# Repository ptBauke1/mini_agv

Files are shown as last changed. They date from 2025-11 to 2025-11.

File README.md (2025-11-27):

# 🤖 Mini AGV - Autonomous Guided Vehicle

Robô seguidor de linha com controle PID, detecção de obstáculos e monitoramento em tempo real via dashboard web.

## 🎯 Sobre o Projeto

Este projeto implementa um AGV (Automated Guided Vehicle) utilizando o microcontrolador **RP2040**, capaz de seguir linhas de forma autônoma com controle PID ajustável, detectar obstáculos e transmitir telemetria em tempo real para um dashboard web.

### Características Principais

- **Seguidor de linha** com 8 sensores infravermelhos multiplexados
- **Controle PID** ajustável em tempo real via Bluetooth
- **Detecção de obstáculos** com sensor ultrassônico HC-SR04
- **Dashboard web** para visualização de telemetria e controle remoto
- **Comunicação Bluetooth** para comandos e telemetria
- **Sistema de calibração** automático dos sensores

---

## ✨ Funcionalidades

- ✅ Seguimento de linha preto/branco com controle PID
- ✅ Detecção e parada automática diante de obstáculos (< 120mm)
- ✅ Telemetria em tempo real (200ms): PWM dos motores, erro de linha, distância
- ✅ Dashboard web com gráficos ao vivo (Chart.js)
- ✅ Comandos via Bluetooth: START, STOP, CALIBRATE, PID
- ✅ Calibração automática dos sensores de linha
- ✅ Ajuste de constantes PID em tempo real
- ✅ Controle de velocidade base dos motores

---

## 🔧 Hardware

### Lista de Materiais

#### Barra de Sensor

| Componente | Quantidade | Descrição |
|---|---|---|
| **Sensor de linha IR** | 8 | QRE1113 |
| **Resistor 220 Ohms** | 8 | 220 Ohms |
| **Resistor 22k Ohms** | 8 | 22k Ohms|
| **CD4051** | 1 | Multiplexador analógico 8:1 |

#### Placa Principal

| Componente | Quantidade | Descrição |
|---|---|---|
| **Raspberry Pi Pico** | 1 | Microcontrolador principal (RP2040) |
| **HC-SR04** | 1 | Sensor ultrassônico para detecção de obstáculos |
| **L298N** | 1 | Drivers de motor DC (ou 1 módulo duplo) |
| **Motor DC** | 2 | Motores DC 3-6V |
| **HC-05/06** | 1 | Módulo Bluetooth (UART) |
| **LM7805** | 1 | Regulador 5V |
| **LM1117** | 1 | Regulador 3v3|
| **Capacitor 10uF** | 4 | Capacitor Eletrolitico 10uF |
| **Resistor 10k Ohms**| 4 | Resistor 10k Ohms |
| **2N7000** | 2 | MOSFET 2N7000 |
| **Diodo** | 1 | Diodo 1N4007 |

#### Chassi
| Componente | Quantidade | Descrição |
|---|---|---|
| **Placa de MDF** | 1 | Placa de MDF de 3mm para corte do chassi |
| **Rodas** | 2 | Rodas de 65mm |
| **PLA** | 1 | Carretel de filamento PLA para impressão de peças |
| **Elasticos** | 10 | Elasticos de dinheiro para serem colocados nas rodas |
| **Parafusos e Porcas** | 6 | Parafusos e Porcas M3 |
| **Feltro** | 1 | Feltro para terceiro ponto de apoio |
### Pinagem

| Periférico | Pino(s) Pico W | Descrição |
|---|---|---|
| **Bluetooth (UART1)** | GPIO 8 (TX), GPIO 9 (RX) | Comunicação serial 9600 baud |
| **Ultrassônico** | GPIO 2 (TRIG), GPIO 3 (ECHO) | Medição de distância |
| **Sensores de Linha** | GPIO 18, 19, 20 (Mux S0-S2), GPIO 26 (ADC0) | 8 sensores via multiplexador |
| **Motor Esquerdo** | GPIO 11 (ENA), GPIO 14 (IN1A), GPIO 15 (IN2A) | Controle PWM + direção |
| **Motor Direito** | GPIO 10 (ENB), GPIO 12 (IN1B), GPIO 13 (IN2B) | Controle PWM + direção |

---

## 💻 Software

### Tecnologias Utilizadas

#### Firmware (C++)
- **Pico SDK 2.2.0** - Framework oficial da Raspberry Pi
- **C++17** - Linguagem principal
- **CMake** - Sistema de build
- **bt_kmn** - Biblioteca customizada para Bluetooth com sistema de comandos

#### Dashboard (Web)
- **Python 3.x** - Servidor WebSocket/HTTP
- **asyncio + websockets** - Comunicação assíncrona
- **pyserial** - Interface com porta serial Bluetooth
- **HTML5 + JavaScript** - Frontend do dashboard
- **Chart.js** - Visualização de telemetria em tempo real

### Arquitetura

```
Raspberry Pi Pico (Firmware C++)
         ↓ Bluetooth UART (9600 baud)
    Módulo HC-05/06
         ↓ USB Serial (COM Port)
 Computador (Python Server)
         ↓ WebSocket (8765)
   Dashboard Web (HTML/JS)
```

---

## 🔨 Montagem

### Esquemas de Ligação

#### Esquema Principal - Motores, Bluetooth e Ultrassônico

<p align="center">
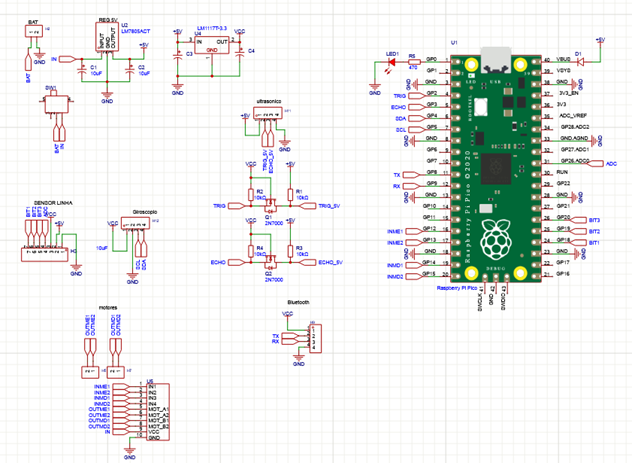
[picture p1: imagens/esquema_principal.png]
Esquema Principal
  
</p>

#### Esquema dos Sensores de Linha (Multiplexador)

<p align="center">
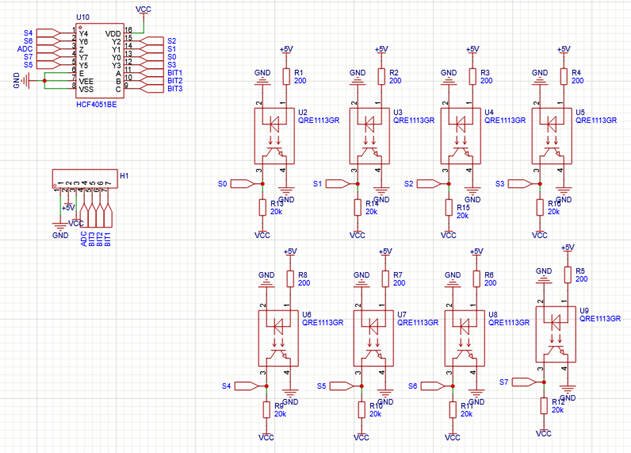
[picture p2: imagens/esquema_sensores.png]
Esquema Sensores
  
</p>

### Foto da Montagem Final

<p align="center">
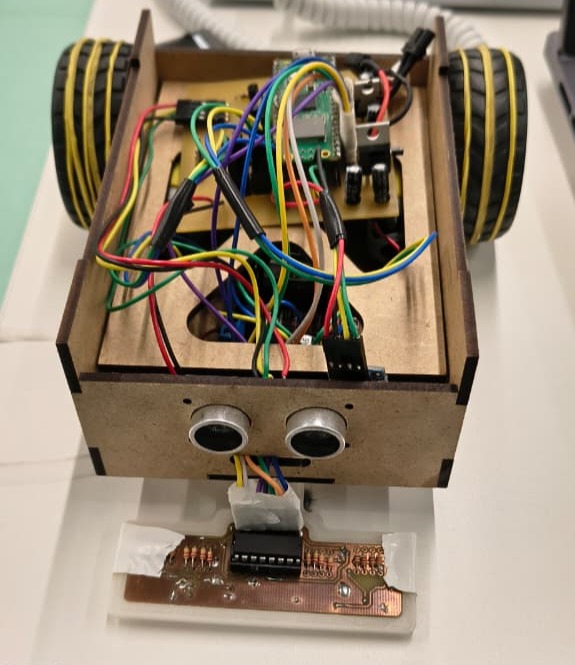
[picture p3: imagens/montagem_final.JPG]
Montagem Final
  
</p>

<p align="center"><em>Robô montado com todos os componentes integrados</em></p>
---

## 🚀 Instalação e Configuração

### Pré-requisitos

- **Raspberry Pi Pico SDK** (2.2.0 ou superior)
- **CMake** (3.13+)
- **Ninja** (build system)
- **Python 3.8+** com pip
- **Git** (para clonar submódulos)

### Passo 1: Clonar o Repositório

```bash
git clone https://github.com/ptBauke1/mini_agv.git
cd mini_agv
git submodule update --init --recursive
```

### Passo 2: Compilar o Firmware

```bash
# Criar diretório de build
mkdir build
cd build

# Configurar CMake
cmake ..

# Compilar
ninja
```

O arquivo `projeto_agvs.uf2` será gerado em `build/`.

### Passo 3: Instalar Dependências Python (Dashboard)

```bash
cd dashboard
python -m venv .venv
source .venv/bin/activate  # Linux/Mac
# ou
.venv\Scripts\activate     # Windows

pip install asyncio websockets pyserial
```

### Passo 4: Flashear o Pico W

1. Conecte o Pico W ao PC segurando o botão **BOOTSEL**
2. Copie `build/projeto_agvs.uf2` para o drive USB que apareceu
3. O Pico reiniciará automaticamente com o novo firmware

---

## 🎮 Uso

### Iniciar o Sistema

1. **Ligar o robô** (conectar bateria)
2. **Conectar o módulo Bluetooth** ao computador
3. **Iniciar o servidor Python**:
   ```bash
   cd dashboard
   python bt_websocket_server.py
   ```
4. **Abrir o dashboard** no navegador:
   ```
   http://localhost:8080/dashboard.html
   ```

### Calibração dos Sensores

1. No dashboard, clique em **"Connect WS"** para conectar ao servidor
2. Selecione a porta COM do Bluetooth e clique em **"Connect COM"**
3. Posicione o robô sobre a linha (metade dos sensores no preto, metade no branco)
4. Clique em **"🎯 Calibrate Sensors"**
5. **Movimente o robô lentamente** sobre a linha por ~10 segundos
6. Aguarde a mensagem "Calibration COMPLETE"

### Operação Normal

1. Posicione o robô sobre a linha
2. Clique em **"▶️ Start Robot"**
3. Ajuste constantes PID se necessário (painel "⚙️ PID Control")
4. Monitore telemetria em tempo real nos gráficos

---

## 📊 Dashboard Web

### Recursos do Dashboard

- **Status de Conexão**: WebSocket e COM Port separados
- **Controles do Robô**: START, STOP, CALIBRATE
- **Painel PID**: Ajuste de Kp, Ki, Kd em tempo real
- **Indicador de Obstáculos**: Visual + alerta sonoro (animado)
- **Métricas Instantâneas**: PWM motores, erro de linha, distância
- **Gráficos em Tempo Real**: 
  - PWM dos motores (esquerdo/direito)
  - Erro do seguidor de linha
  - Distância do sensor ultrassônico
- **Log de Dados**: Histórico de comandos e eventos

### Captura de Tela

<p align="center">
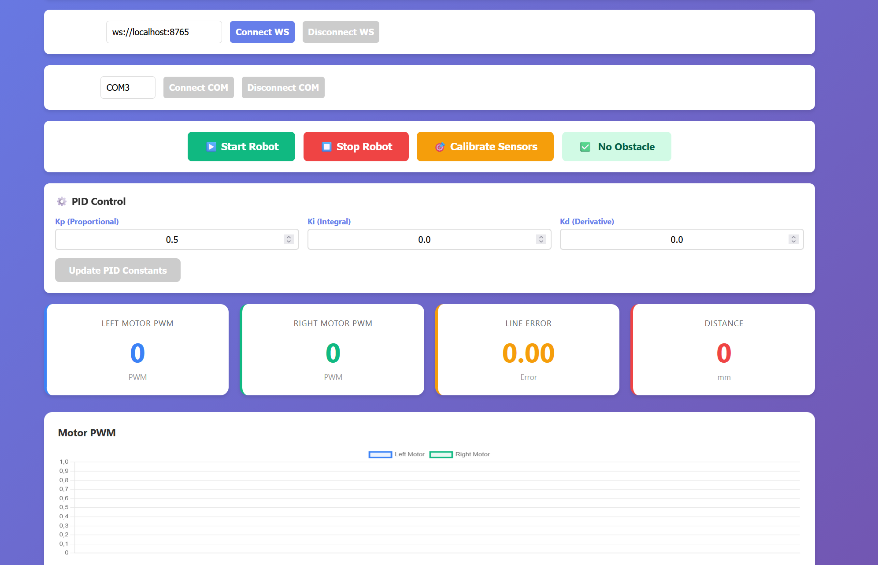
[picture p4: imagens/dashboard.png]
Dashboard Web
  
</p>

<p align="center"><em>Interface do dashboard com gráficos em tempo real e controles do robô</em></p>

---

## 📡 Comandos Bluetooth

O robô aceita os seguintes comandos via Bluetooth (9600 baud, `\n` terminador):

### Comandos Básicos

| Comando | Formato | Descrição | Resposta |
|---|---|---|---|
| **START** | `START` | Inicia o robô | `Robot STARTED` |
| **STOP** | `STOP` | Para o robô e motores | `Robot STOPPED` |
| **CALIBRATE** | `CALIBRATE` | Calibra sensores de linha | `Calibration COMPLETE` |

### Ajuste de PID

| Comando | Formato | Exemplo | Descrição |
|---|---|---|---|
| **PID** | `PID <kp> <ki> <kd>` | `PID 0.3 0.0 0.02` | Define constantes PID |
| **PID** | `PID` (sem parâmetros) | `PID` | Consulta valores atuais |

**Resposta**: `PID updated: Kp=0.300 Ki=0.000 Kd=0.020`

### Formato de Telemetria

A cada 200ms, o robô envia automaticamente:
```
L:<left_pwm>,R:<right_pwm>,E:<error>,D:<distance>
```
**Exemplo**: `L:850,R:750,E:-1.25,D:350`

Veja [COMMANDS.md](COMMANDS.md) para documentação completa.

---

## 📁 Estrutura do Projeto

```
projeto_agvs/
├── CMakeLists.txt              # Configuração CMake principal
├── projeto_agvs.cpp            # Código principal (main loop, PID)
├── pico_sdk_import.cmake       # Importação do Pico SDK
├── COMMANDS.md                 # Documentação detalhada de comandos
├── README.md                   # Este arquivo
│
├── include/                    # Headers personalizados
│   ├── sensors.hpp             # Sensores de linha + ultrassônico
│   ├── motors.hpp              # Controle de motores L298N
│   ├── gyro.hpp                # Giroscópio MPU6050
│   └── agv_commands.h          # Sistema de comandos
│
├── src/                        # Implementações
│   ├── sensors.cpp
│   ├── motors.cpp
│   ├── gyro.cpp
│   └── agv_commands.cpp        # Comandos Bluetooth (START, STOP, PID, etc.)
│
├── bluetooth_sdk/              # Biblioteca bt_kmn (submódulo)
│   ├── include/bt_kmn/
│   │   ├── bluetooth.h
│   │   └── commands.h
│   └── src/
│       ├── bluetooth.c
│       └── commands.c
│
├── dashboard/                  # Interface web
│   ├── bt_websocket_server.py # Servidor Python (WebSocket + Serial)
│   └── dashboard.html          # Frontend (Chart.js + controles)
│
└── build/                      # Arquivos de compilação (gerado)
    └── projeto_agvs.uf2        # Firmware final
```

---

## 🔬 Algoritmo de Controle

### Controle PID

O robô utiliza um controlador PID para seguir a linha:

```
erro = posição_calculada - centro_linha
integral += erro
derivada = erro - erro_anterior
correção = Kp × erro + Ki × integral + Kd × derivada

pwm_esquerdo = base_speed + correção
pwm_direito = base_speed - correção
```

**Valores padrão**:
- Kp = 1.75 (proporcional)
- Ki = 0.0 (integral - desabilitado para evitar overshooting)
- Kd = 520.0 (derivativo)
- Base Speed = 800 (PWM de 0-1023)

### Detecção de Obstáculos

- Leitura do ultrassônico a cada 10ms
- Limiar de parada: **120mm**
- Timeout de leitura: 50ms
- Ação: Para motores automaticamente (`robot_enabled = false`)

---

## 🐛 Troubleshooting

### Problema: Sensores de linha não calibram corretamente
**Solução**: 
- Verificar se os 8 sensores estão conectados ao multiplexador
- Aumentar contraste da linha (preto mais escuro, branco mais claro)
- Ajustar altura dos sensores (3-5mm da superfície)

### Problema: Ultrassônico retorna 0 ou 65535
**Solução**:
- Verificar pino ECHO (deve estar em nível lógico compatível - usar divisor de tensão se necessário)
- Aumentar timeout em `sensors.cpp` (padrão 50ms)
- Verificar alimentação do HC-SR04 (5V estável)

### Problema: Dashboard não conecta
**Solução**:
- Verificar firewall (liberar porta 8765 WebSocket + 8080 HTTP)
- Conferir porta COM do Bluetooth (ajustar em `bt_websocket_server.py` ou no dashboard)
- Testar comunicação serial: `python -m serial.tools.miniterm COM3 9600`

### Problema: Motores não respondem
**Solução**:
- Verificar alimentação dos drivers L298N (bateria carregada)
- Conferir jumpers de enable nos L298N
- Testar PWM com osciloscópio/LED (pinos 10 e 11 do Pico)

---

## 📚 Referências

- [Raspberry Pi Pico SDK Documentation](https://www.raspberrypi.com/documentation/pico-sdk/)
- [Chart.js Documentation](https://www.chartjs.org/docs/)

---

**Última atualização**: Novembro 2025

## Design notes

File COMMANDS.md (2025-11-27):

# Comandos Bluetooth do AGV

Este documento descreve todos os comandos disponíveis para controle do AGV via Bluetooth.

## Sistema de Comandos

Os comandos seguem o formato da biblioteca `bt_kmn`:
- Comandos simples: `COMANDO\n`
- Comandos com parâmetros: `COMANDO=parametros\n`

## Lista de Comandos

### 1. START
**Uso**: `START`  
**Descrição**: Inicia o robô e habilita o seguidor de linha  
**Exemplo**:
```
START
```
**Resposta**: `Robot STARTED`

---

### 2. STOP
**Uso**: `STOP`  
**Descrição**: Para o robô imediatamente e desabilita todos os motores  
**Exemplo**:
```
STOP
```
**Resposta**: `Robot STOPPED`

---

### 3. STATUS
**Uso**: `STATUS`  
**Descrição**: Retorna o estado atual do robô (rodando ou parado)  
**Exemplo**:
```
STATUS
```
**Resposta**: `Robot is RUNNING` ou `Robot is STOPPED`

---

### 4. SPEED
**Uso**: `SPEED=<valor>` ou `SPEED` (consulta)  
**Descrição**: Define ou consulta a velocidade base dos motores  
**Parâmetros**:
- `valor`: Velocidade entre 0 e 1000 (PWM)

**Exemplos**:
```
SPEED=500        # Define velocidade para 500
SPEED            # Consulta velocidade atual
```
**Resposta**: `Base speed set to 500` ou `Current speed: 500`

---

### 5. PID
**Uso**: `PID=<kp>,<ki>,<kd>` ou `PID` (consulta)  
**Descrição**: Define ou consulta as constantes do controlador PID  
**Parâmetros**:
- `kp`: Constante proporcional
- `ki`: Constante integral
- `kd`: Constante derivativa

**Exemplos**:
```
PID=1.5,0.0,0.5  # Define Kp=1.5, Ki=0.0, Kd=0.5
PID              # Consulta valores atuais
```
**Resposta**: `PID set to Kp=1.500 Ki=0.000 Kd=0.500`

---

### 6. HELP
**Uso**: `HELP`  
**Descrição**: Lista todos os comandos disponíveis  
**Exemplo**:
```
HELP
```
**Resposta**: Lista formatada de comandos

---

## Telemetria Automática

O AGV envia automaticamente dados de telemetria a cada 200ms:

**Formato**: `L:<pwm_esq>,R:<pwm_dir>,E:<erro>,D:<distancia>\n`

**Exemplo**:
```
L:150,R:180,E:1.23,D:450
```

Onde:
- `L`: PWM do motor esquerdo (0-255)
- `R`: PWM do motor direito (0-255)
- `E`: Erro do seguidor de linha (float)
- `D`: Distância do obstáculo em mm

---

## Usando via Dashboard Web

O dashboard web envia comandos automaticamente quando você clica nos botões:
- **▶️ Start Robot** → envia `START`
- **⏹️ Stop Robot** → envia `STOP`

---

## Usando via Terminal Serial

Você pode enviar comandos manualmente usando qualquer terminal serial (PuTTY, Arduino IDE, etc.):

1. Conecte à porta COM do Bluetooth (9600 baud)
2. Digite o comando seguido de Enter
3. Observe a resposta

**Exemplo de sessão**:
```
> HELP
=== AGV Commands ===
START        - Start robot
STOP         - Stop robot
...

> START
Robot STARTED

> SPEED=600
Base speed set to 600

> STATUS
Robot is RUNNING

> STOP
Robot STOPPED
```

---

## Adicionando Novos Comandos

Para adicionar um novo comando, edite `src/agv_commands.cpp`:

```cpp
// Command: MEU_COMANDO
// Usage: MEU_COMANDO=<param>
// Description: Descrição do comando
BT_COMMAND_DEFINE(MEU_COMANDO) {
    // params contém os parâmetros após o '='
    // Implemente a lógica aqui
    
    Bluetooth_SendMessage("Resposta do comando\n");
}
```

O sistema de comandos usa macros da biblioteca `bt_kmn` para registrar automaticamente os comandos disponíveis.

---

## Notas Técnicas

1. **Terminação**: Todos os comandos devem terminar com `\n`
2. **Case Sensitive**: Os comandos são case-sensitive (use maiúsculas)
3. **Buffer**: Comandos limitados a 128 caracteres
4. **Delimitador**: Parâmetros são separados por `=`
5. **Múltiplos Parâmetros**: Use vírgulas: `CMD=param1,param2,param3`

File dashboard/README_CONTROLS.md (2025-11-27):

# Sistema de Controle Remoto do AGV

## Funcionalidades Adicionadas

### 1. **Botões de Controle**
- **▶️ Start Robot**: Inicia o movimento do AGV (habilita motores)
- **⏹️ Stop Robot**: Para o AGV imediatamente (desabilita motores)

### 2. **Indicador de Obstáculos**
- **✅ No Obstacle**: Exibido quando não há obstáculos detectados
- **⚠️ Obstacle at Xmm**: Pisca em vermelho quando um obstáculo é detectado a menos de 120mm
- Animação de pulso para alertar visualmente

## Arquitetura

### Fluxo de Comandos
```
Dashboard → WebSocket → Python Server → Serial/Bluetooth → Microcontrolador
```

### Fluxo de Detecção de Obstáculos
```
Sensor Ultrassônico → Microcontrolador → Bluetooth → Python → WebSocket → Dashboard
```

## Protocolo de Comunicação

### Comandos (Dashboard → MCU)
- `CMD:START\n` - Inicia o robô
- `CMD:STOP\n` - Para o robô

### Telemetria (MCU → Dashboard)
- `L:<pwm>,R:<pwm>,E:<erro>,D:<distancia>\n` - Dados em tempo real

## Comportamento do Sistema

### Estado Inicial
- Robô desabilitado (motores parados)
- Aguardando comando START

### Após START
- Motores habilitados
- Seguidor de linha ativo
- Detecção de obstáculos ativa
- Se obstáculo < 120mm → motores param automaticamente

### Após STOP
- Motores desabilitados imediatamente
- Telemetria continua sendo enviada
- Sensores continuam lendo (sem atuação)

## Segurança

1. **Parada de Emergência**: Botão STOP funciona a qualquer momento
2. **Detecção Automática**: Obstáculos param o robô mesmo sem comando
3. **Estado Persistente**: Robô sempre inicia desabilitado
4. **Feedback Visual**: Indicador de obstáculo em tempo real

## Uso

1. Conecte o dashboard ao WebSocket
2. Aguarde telemetria (confirma conexão)
3. Clique **START** quando pronto
4. Monitore obstáculos no indicador
5. Use **STOP** para parada de emergência

## Detalhes Técnicos

- **Threshold de Obstáculo**: 120mm
- **Taxa de Atualização**: 200ms (5Hz)
- **Latência de Comando**: <50ms
- **Animação de Alerta**: 1s pulse cycle

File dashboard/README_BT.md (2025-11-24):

# Bluetooth Telemetry Receiver

## Installation

1. Install Python packages:
```bash
pip install pyserial matplotlib websockets
```

## Usage Options

### 1. Simple Console Output (`bt_receiver.py`)

Quick view of telemetry in the terminal.

```bash
python bt_receiver.py
```

### 2. Interactive Matplotlib Dashboard (`bt_dashboard.py`)

Real-time graphs with matplotlib (desktop app).

```bash
python bt_dashboard.py
```

### 3. HTML Web Dashboard (`dashboard.html` + `bt_websocket_server.py`)

Modern web-based dashboard accessible from any browser!

**Steps:**
1. Edit `bt_websocket_server.py`:
   - Change `SERIAL_PORT = 'COM3'` to your actual port

2. Start the WebSocket server:
```bash
python bt_websocket_server.py
```

3. Open `dashboard.html` in your web browser

4. Click "Connect" button in the dashboard

**Features:**
- 📊 Real-time charts with Chart.js
- 💎 Modern, beautiful UI
- 📱 Responsive design
- 📝 Live data log
- 🎨 Color-coded metrics

## Configuration

For all scripts, find your Bluetooth COM port:
- Open Device Manager → Ports (COM & LPT)
- Look for your Bluetooth device (e.g., COM3, COM4)

## Output Example (Console)
```
[14:23:45] Left PWM:  650 | Right PWM:  750 | Error:  -1.23 | Distance:  245 mm
[14:23:46] Left PWM:  680 | Right PWM:  720 | Error:   0.45 | Distance:  243 mm
```

## Troubleshooting

- **"Access denied"**: Close any other program using the COM port
- **"Port not found"**: Check the COM port number in Device Manager
- **No data**: Make sure the Bluetooth connection is established
- **WebSocket error**: Ensure the server is running before opening the HTML dashboard

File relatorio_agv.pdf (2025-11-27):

Plataforma autônoma para logística

Eliana So 1

; Pedro Bauke 1

; Andressa Martins 2

; Rodrigo França 2

1 Aluno do Instituto Mauá de Tecnologia (IMT); 2 Professor do Instituto Mauá de Tecnologia (IMT).

Resumo. Este projeto apresenta o desenvolvimento de um protótipo de Veículo Guiado Autonomamente (AGV) voltado para a logística interna, motivado pela crescente demanda do e-commerce no Brasil. A plataforma robótica foi construída utilizando materiais acessíveis, como MDF e impressão 3D, e é controlada por um microcontrolador RP2040. O sistema de navegação baseia-se na leitura de linha por meio de sensores de refletância e um algoritmo de controle PID, integrando também detecção de obstáculos via ultrassom e telemetria em tempo real via Bluetooth para um dashboard web. Durante os testes, desafios relacionados à aderência mecânica e ao driver de potência exigiram a substituição de componentes (do driver MX1508 para o L298N) e adaptações nas rodas. Apesar das dificuldades e da não implementação do módulo inercial (MPU) devido ao prazo, o protótipo final atingiu os objetivos propostos, demonstrando capacidade de navegar autonomamente, interromper o movimento ao detectar obstáculos e comunicar dados operacionais com sucesso.

Introdução

O varejo online tem, cada vez mais, se tornado a opção primária para compras dos brasileiros, como mostra um estudo realizado pela FGV, que expõe que as vendas do e-commerce já representam mais de 10% do faturamento do setor desde outubro de 2021 e em fevereiro de 2025 chegaram a representar 17,8%. A Figura 1 apresenta um histórico da parcela do e-commerce no varejo.

Figura 1 – Fatia de e-commerce no varejo

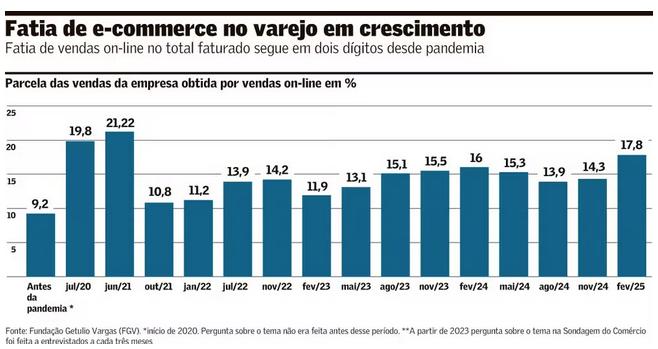
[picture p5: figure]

Fonte: Valor Econômico (2025)

Olhando para esse cenário, diversas empresas estão investindo em centros de distribuição e logística, e maneiras de automatizar esses centros. Uma dessas maneiras é com a utilização de AGVs (Autonomous Guided Vehicles), ou robôs autônomos que são capazes de se movimentar e carregar cargas dentro dos armazéns, facilitando e agilizando a logística.

Observando essa tendência, optou-se pelo desenvolvimento de um protótipo de uma plataforma capaz de detectar obstáculos e navegar de forma autônoma em ambientes controlados, necessitando apenas de uma linha para poder seguir e andar de um ponto a outro.

Material e Métodos

Por se tratar de um protótipo, optou-se por utilizar materiais de fácil acesso, como MDF e filamento plástico, e métodos de fabricação rápidos, como corte à laser e impressão 3D, para poder iterar de maneira rápida entre versões. A Figura 2 apresenta a montagem final do protótipo.

Figura 2 – Montagem Final

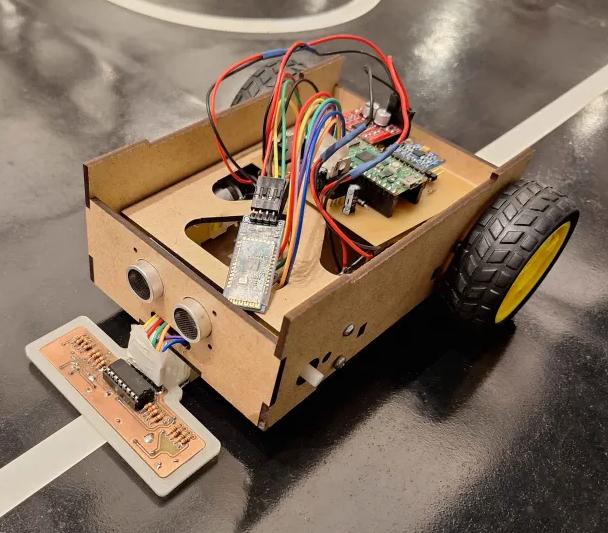
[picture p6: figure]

Fonte: Os Autores (2025)

Mecânica

Por se tratar de um protótipo, o robô possui dimensões pequenas (210 x 155 x 75 mm), a Figura 3 ilustra o projeto mecânico em CAD.

Figura 3 – Vista Explodida em CAD

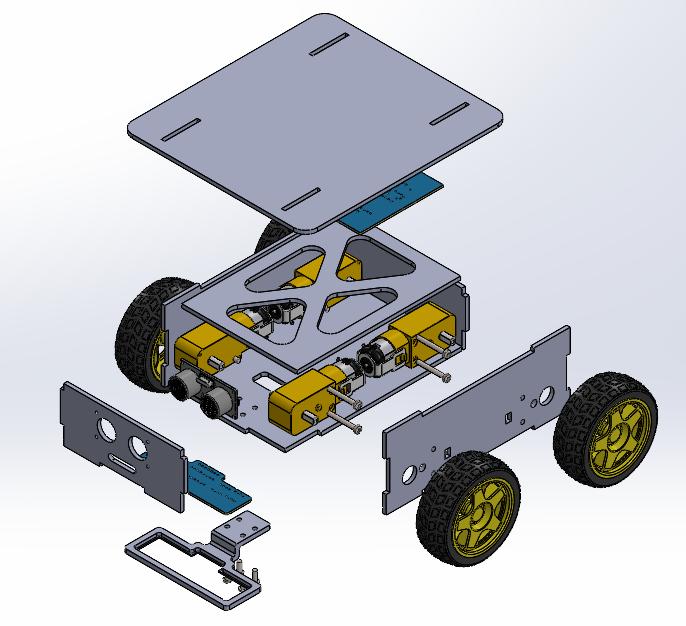
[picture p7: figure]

Fonte: Os autores (2025)

O corpo principal, que possui um formato de caixa, é formado por chapas de MDF fabricadas por corte a laser. Dentro comporta-se os motores, a placa eletrônica principal e o sensor ultrassônico. O robô utiliza-se de 4 motores DC com caixa de redução para ser capaz de transportar objetos mais pesados, devido à melhor distribuição de peso e torque. As rodas são de 65mm de diâmetro e possuem pneus de borracha com um encaixe para os motores.
Foi feito um suporte em impressão 3D, preso por parafusos, para comportar a barra de sensores frontal e mantêm uma distância de 5mm entre o chão e os sensores para a diminuição de erros de leitura.
A mesa superior, onde ficam os itens os quais querem ser movidos, é feito de MDF de 3 mm e é modular, podendo-se criar outros formatos, desde que possuam os encaixes corretos.

Eletrônica

Para a criação e fabricação das placas de circuito impresso,foi montado o diagrama de blocos ilustrado pela Figura 4, que representa de forma simples e clara como cada elemento do circuito se comunica, explicitando como os componentes trocam informações entre si.

Figura 4 – Diagrama de blocos do sistema

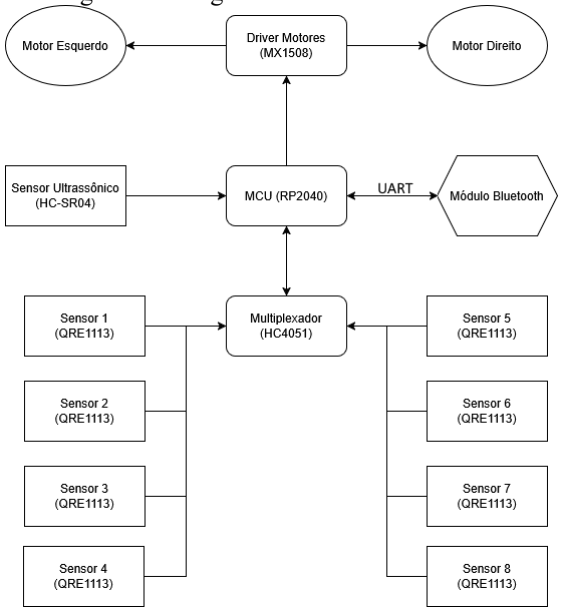
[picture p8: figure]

Fonte: Os Autores (2025)

Optou-se por ter duas placas de circuito separadas, para facilitar a montagem, pois os sensores utilizados para “enxergar” a linha precisam estar próximos ao chão. As Figuras 5 e 6 apresentam os esquemas elétricos das duas placas.

Figura 5 – Esquema elétrico da placa de controle

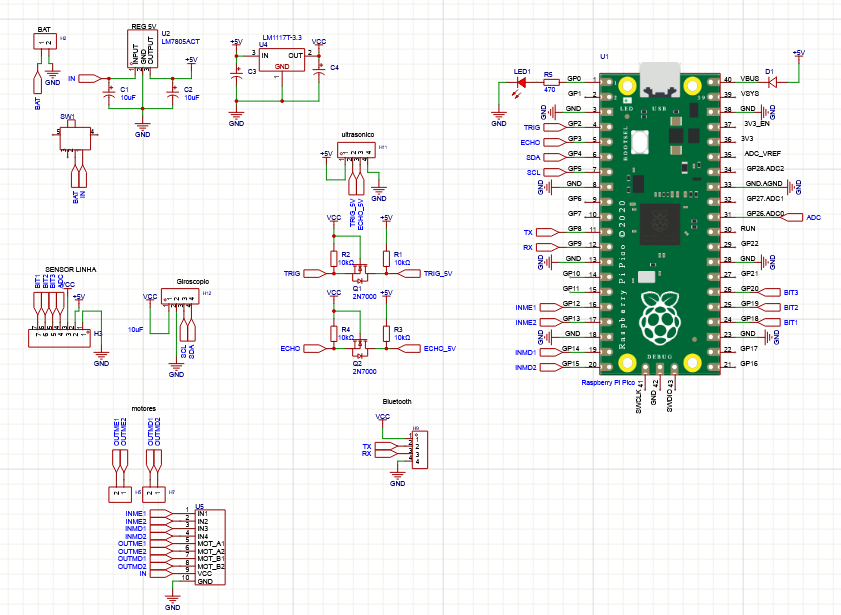
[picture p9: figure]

Fonte: Os Autores (2025)

Figura 6 – Esquema elétrico da placa de sensores

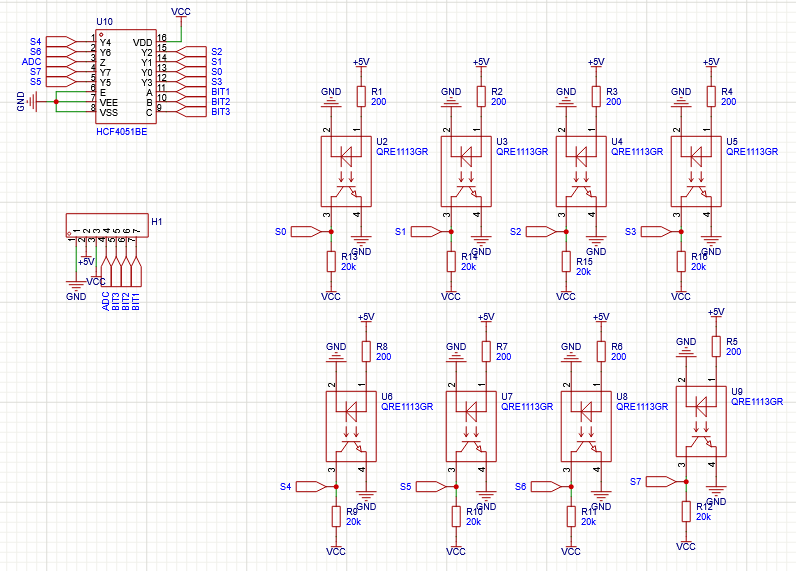
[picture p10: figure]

Fonte: Os Autores (2025)

Na placa dos sensores estão localizados os 8 sensores de refletância QRE1113 e o multiplexador analógico HC4051, que possui 8 canais e é responsável por garantir que todos os sensores possam ser lidos pelo microcontrolador, uma vez que o RP2040 apresenta apenas 3 canais ADC disponíveis. A Figura 7 apresenta a barra dos sensores com os componentes já soldados.

Figura 7 – Barra dos Sensores

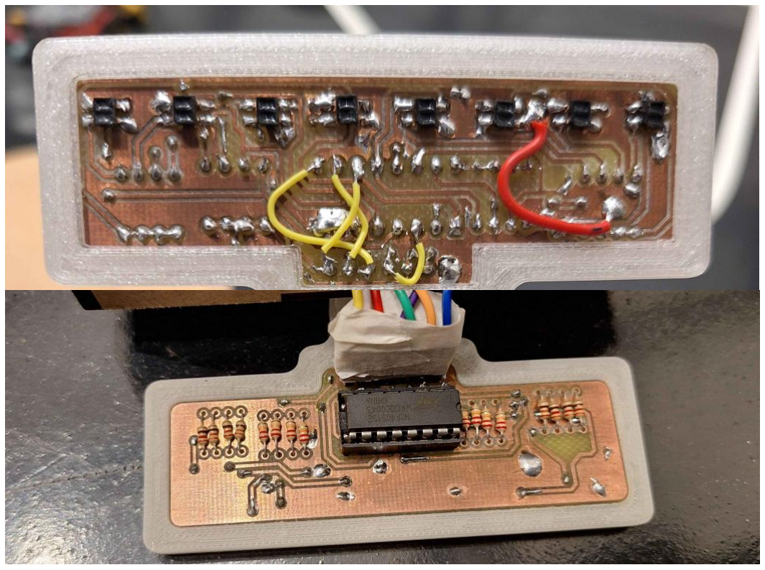
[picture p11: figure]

Fonte: Os Autores (2025)

Para comunicar com o multiplexador é preciso escolher qual porta se deseja ler, para isso, 3 GPIOs do microcontrolador são conectados aos pinos de controle do CI para realizar essa seleção via software.
A PCB de controle contém o microcontrolador e os demais componentes para o funcionamento do robô. Nessa placa também se conecta a bateria, LiPo de 2 células, que alimenta o projeto pois os motores escolhidos suportam até 9V. Para alimentar os demais componentes existem dois reguladores de tensão no circuito, utiliza-se do LM7805 para gerar uma tensão de 5V e um LM1117 que gera a tensão de 3,3V, como pode ser visto na Figura 8.

Figura 8 – Placa de controle

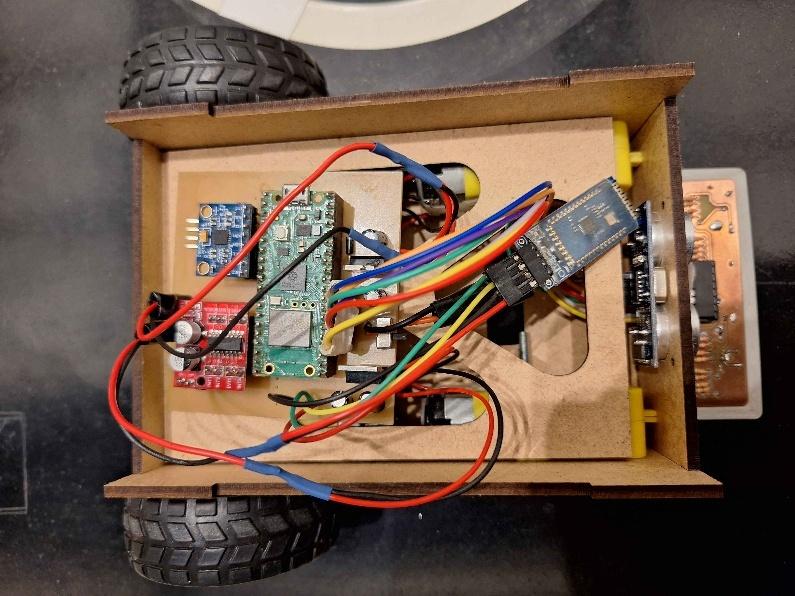
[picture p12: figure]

Fonte: Os Autores (2025)

Para o controle dos motores foi escolhido o Driver MX1508, é uma ponte H dupla onde recebe sinais PWM do microcontrolador e transforma em direção e velocidade aos motores DC. Adicionou-se uma MPU (acelerômetro e giroscópio) com o objetivo de obter a orientação do robô em um determinado percurso a partir da integração da aceleração obtida.

Na placa principal se encontra um módulo bluetooth, responsável por enviar informações do robô, como duty cicle do PWM de cada motor e o erro da leitura dos sensores de linha para um computador de apoio, que apresenta esses dados em um dashboard.

Código

O software do robô é escrito em C++, utilizando-se de classes e objetos para criar um código de fácil entendimento e manutenção. Além disso, cada classe está localizada em seu próprio par de arquivos header e cpp. O arquivo principal do programa contém a declaração de todas as classes utilizadas, uma interrupção de timer e o loop principal. O código completo pode ser visualizado no repositório do projeto no GitHub. (https://github.com/ptBauke1/mini_agv) A Figura 9 apresenta o fluxograma do sistema.

Figura 9 – Fluxograma

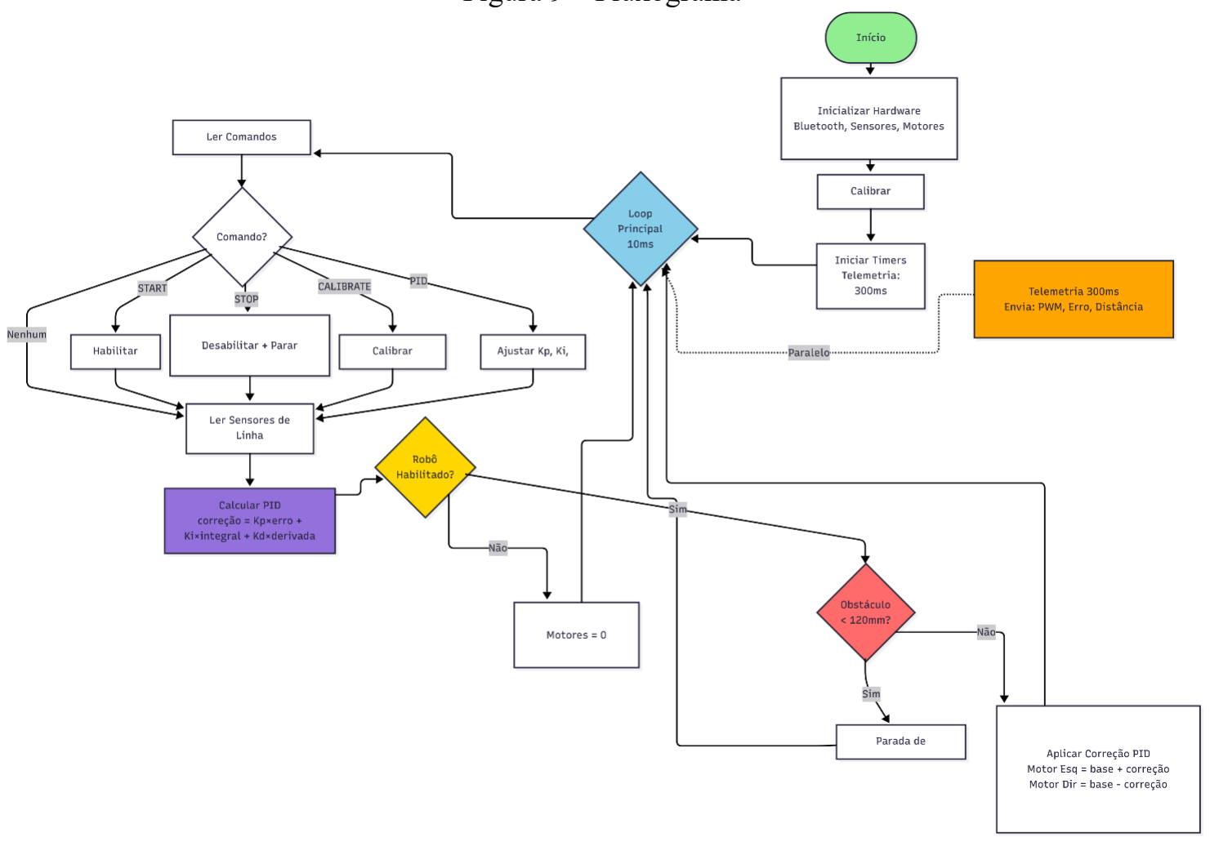
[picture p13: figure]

Fonte: Os Autores (2025)

Para controlar os motores, criou-se a classe Motor, que configura dois canais de PWM para atuarem a 20kHz de frequência, com um wrap máximo de 1023, para se ter uma resolução de aproximadamente 7,8mV.
O método set_speed recebe como argumento um número inteiro, checa se esse valor está dentro do intervalo permitido e a partir do sinal desse valor habilita um dos canais de PWM, uma vez que o driver utilizado possui apenas duas entradas de PWM, e a direção de rotação do motor é escolhida a partir de qual canal está ativo.
A classe SensorArray é responsável por controlar o multiplexador e realizar a leitura dos sensores. Para garantir uma leitura mais estável e homogênea entre os sensores, é realizada uma calibração no momento que o robô é ligado, guardando em arrays as leituras máximas e mínimas de cada um dos oito sensores, que são usadas posteriormente para realizar uma troca de escala na leitura dos sensores.

O controle do multiplexador é realizado pelo método _set_mux_channel que recebe o canal que se deseja ler como um número inteiro, e utilizando operações de bit shift para a direita, configura os GPIOs de controle para selecionar a porta correta.
O método que retorna a leitura dos sensores para o programa principal é o calculate_error, que realiza a leitura dos sensores e calcula uma média ponderada dos pesos de cada um dos sensores, a Equação 1 apresenta a fórmula utilizada para o cálculo dessa média.

error = (
∑ value[i]∗(i∗1000)

7
i=0
∑ value[i]

7
i=0
) − setpoint | (I)

O value[i] representa a leitura do sensor da posição i, onde o sensor mais à esquerda da placa se encontra na posição 0 e o mais à direita, na 7, normalizado para uma escala de 0 a 1000, e o termo (i ∗ 1000) apresenta o peso atribuído ao respectivo sensor. A equação retorna um valor que pode variar entre 0 e 7000, de acordo com o deslocamento do robô em relação a linha. A Equação 2 demonstra a normalização realizada com a leitura dos sensores.

value[i] =

(raw[i]− min[i])∗1000
(max[i]−min[i])

(II)

Onde value[i] apresenta o valor normalizado, raw[i], a leitura bruta do ADC, e max [i] e min [i], os máximos e mínimos do sensor em questão, obtidos pela calibração.
O sensor ultrassônico é controlado pela classe Ultrasonic, que ativa o pino trigger do sensor por um breve período e calcula a distância dos objetos na frente do robô utilizando a Equação 3.

distancemm =

pulseDuration∗343
(2∗1000)

(III)

O valor de pulseDuration é obtido calculando a duração do sinal HIGH do pino echo do sensor, o valor de 343 representa a velocidade do som, em m/s. Divide-se por 2 para obter somente o tempo de volta da onda até o sensor.
O loop principal consiste em uma malha de controle que atua para corrigir a posição da plataforma autônoma em relação a linha. A malha tem como período de atuação 10ms e possui um controlador PID que recebe o valor de retorno do método calcuate_erro como entrada. A Equação 4 apresenta a equações de diferenças do controlador utilizado.
correction = kp ∗ error + kd ∗ (error − lastError) + ki ∗ integralError | (IV)

O sensor ultrassônico é lido no início do loop de controle e caso a distância a um objeto seja menor que 120mm, o PWM enviado aos motores é zerado, ou seja, o robô para. Optou-se por esse princípio para se ter uma resposta mais fluída da detecção de objetos.
O envio dos dados de telemetria ocorre através de uma interrupção de timer que acontece a cada 200ms, na qual são enviados os dados atuais de PWM de cada motor, distância medida pelo ultrassônico e o erro dos sensores de linha via Bluetooth (UART1 com 9600 de baudrate) para um computador de apoio. Este executa um servidor WebSocket local desenvolvido em Python que atua como ponte entre a comunicação serial Bluetooth e um dashboard web. O dashboard, hospedado localmente via servidor HTTP, utiliza WebSocket para receber telemetria em tempo real e enviar comandos de controle (START/STOP) de volta ao robô, exibindo gráficos dinâmicos atualizados através da biblioteca Chart.js. A Figura 10 apresenta a tela do dashboard.

Figura 10 – Dashboard

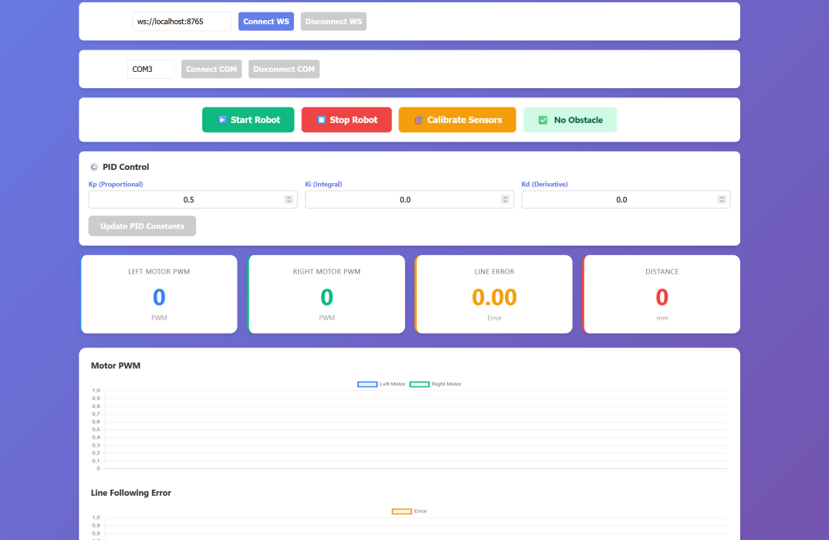
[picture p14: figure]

Fonte: Os Autores (2025)

Resultados e Discussão

Com as PCBs fabricadas, notou-se um pequeno erro no projeto da barra de sensores, algumas conexões do CI multiplexador estavam na camada errada, uma vez que as placas fabricadas no Instituto Mauá de Tecnologia não possuem as vias interligadas.
Foi inserido na placa principal um módulo de medição inercial, porém, optou-se por não o utilizar. Outro problema que foi encontrado durante os testes do protótipo foi a falta de aderência das rodas, fazendo com que o robô derrapasse e por algumas vezes, travasse enquanto tentava andar. Esse problema acabou queimando um dos canais do driver que estava sendo utilizado, por causa disso, ocorreu a troca do driver para um L298N. A Figura 11 apresenta o novo driver utilizado.

Figura 11 – Driver L298N

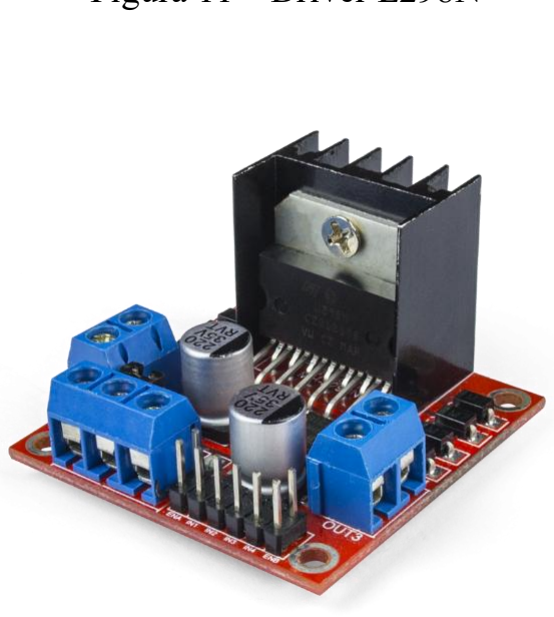
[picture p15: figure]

Fonte: RoboCore (2025)

A principal diferença entre o L298N e o MX1805 é a quantidade de pinos para controle dos drivers. Enquanto o MX1805 necessita de apenas 2 sinais de PWM para seu funcionamento, o L298N necessita de 1 sinal PWM e dois sinais de direção, logo foi preciso reescrever a classe de controle de motor para poder controlar esse novo driver.
Para solucionar o problema de aderência das rodas, colocou-se elásticos nas rodas do projeto. Essa solução se mostrou eficaz, e após essa mudança, o AGV não apresentou mais dificuldades para se movimentar. A Figura 12 mostra como as rodas ficaram com o elástico alocado.

Figura 12 – Rodas com elástico

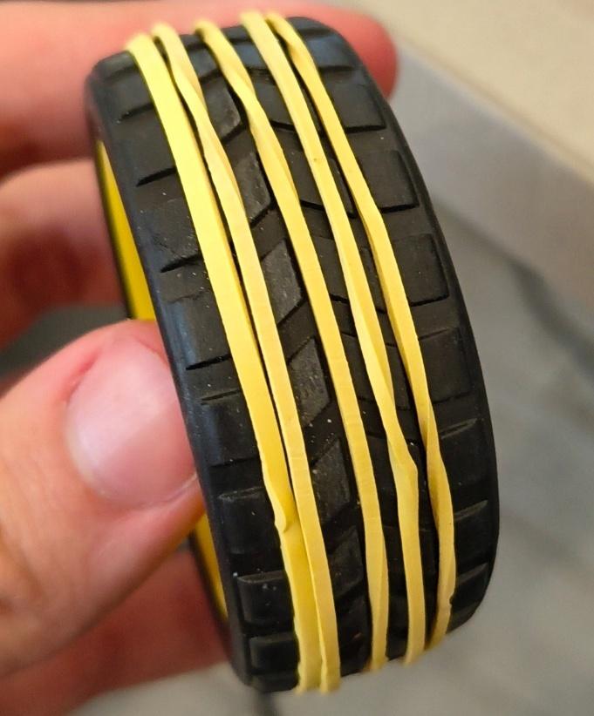
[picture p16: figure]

Fonte: Os Autores (2025)

O controle de quatro motores se mostrou mais difícil que o esperado, principalmente no que se diz respeito ao sincronismo dos motores, por isso, optou-se pelo uso de somente dois, na parte traseira do AGV. Para evitar que os sensores de linha raspassem no chão, um pedaço de feltro foi colado na barra de sensores para servir de terceiro apoio.
Apesar dos problemas encontrados, foi possível fazer com que o protótipo funcionasse da maneira esperada, sendo possível controlar e monitorar o robô a partir do dashboard, além da detecção de obstáculos estar funcionando adequadamente, fazendo com que o robô pare quando um objeto é detectado até 120mm a sua frente.
Por fim, a implementação da MPU não foi possível de ser realizada devido ao prazo de entrega do projeto, porém um software para a leitura dele foi escrito, mas não foi testado extensivamente.

Conclusões

Com base nos resultados apresentados e nas discussões realizadas ao longo do desenvolvimento do projeto, conclui-se que o objetivo de desenvolver uma plataforma autônoma para logística foi alcançado com êxito. O protótipo demonstrou ser capaz de seguir a trajetória estipulada e realizar a parada de segurança ao detectar obstáculos a uma distância de 120mm, validando a lógica de controle e a integração dos sensores.
O projeto evidenciou a importância da iteratividade na engenharia. Problemas críticos encontrados na fase de testes, como a falta de tração das rodas e a queima de canais do driver de motor original, foram solucionados de maneira eficaz através da implementação de elásticos para aumentar o atrito e da substituição do hardware de potência pelo driver L298N. Além disso, a simplificação do sistema de tração de quatro para dois motores traseiros mostrou-se uma decisão acertada para resolver as dificuldades de sincronismo encontradas.

No âmbito do software e eletrônica, a arquitetura baseada no microcontrolador RP2040 e a implementação de classes em C++ permitiram um código organizado e eficiente, facilitando a manutenção e a execução da malha de controle PID de 10ms. A criação de um dashboard web com comunicação via WebSocket provou ser uma ferramenta valiosa para monitoramento e telemetria em tempo real. Embora a integração do sensor inercial (MPU) não tenha sido concluída devido a restrições de prazo, o robô opera funcionalmente dentro das especificações fundamentais estabelecidas.
Dessa forma, o trabalho apresenta um protótipo funcional que serve como prova de conceito para a automação logística de baixo custo, com oportunidades futuras para o aprimoramento da fusão de sensores e navegação inercial.

Referências Bibliográficas

VALOR ECONÔMICO (Brasil). Fatia do on-line no varejo quase dobra desde a pandemia. 2025. Disponível em: https://valor.globo.com/empresas/noticia/2025/03/27/fatia-do-on-line-no-varejo-quase-dobra-desde-a-pandemia.ghtml. Acesso em: 23 nov. 2025.

POUNDER, Les. How to Use an Ultrasonic Sensor with Raspberry Pi Pico. 2021. Disponível em: https://www.tomshardware.com/how-to/raspberry-pi-pico-ultrasonic-sensor. Acesso em: 25 nov. 2025.

RASPBERRY PI FOUNDATION. RP2040 Datasheet: a microcontroller by raspberry pi. A
Microcontroller | by | Raspberry | Pi. | 2025. | Disponível | em: | https://pip-
assets.raspberrypi.com/categories/814-rp2040/documents/RP-008371-DS-1-rp2040-datasheet.pdf?disposition=inline. Acesso em: 27 nov. 2025.

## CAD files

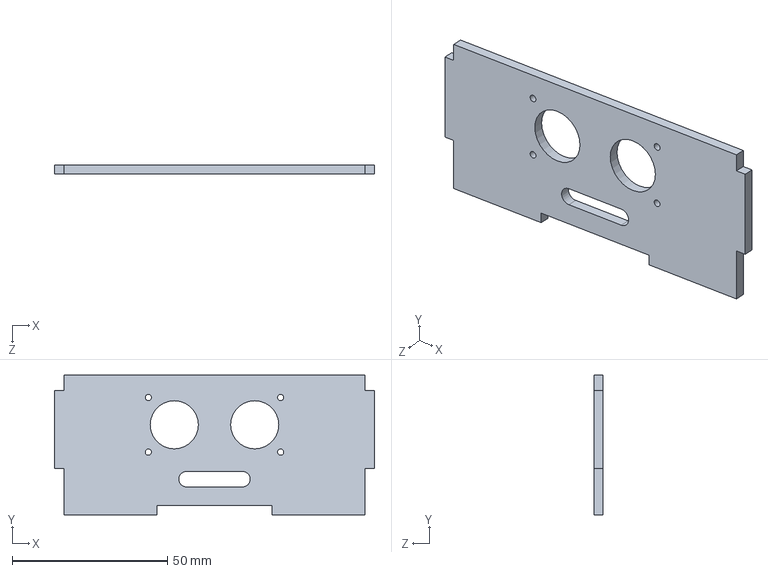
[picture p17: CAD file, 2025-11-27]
projeto_mecanico/frente.SLDPRT
103.0 x 45.0 x 3.00 mm

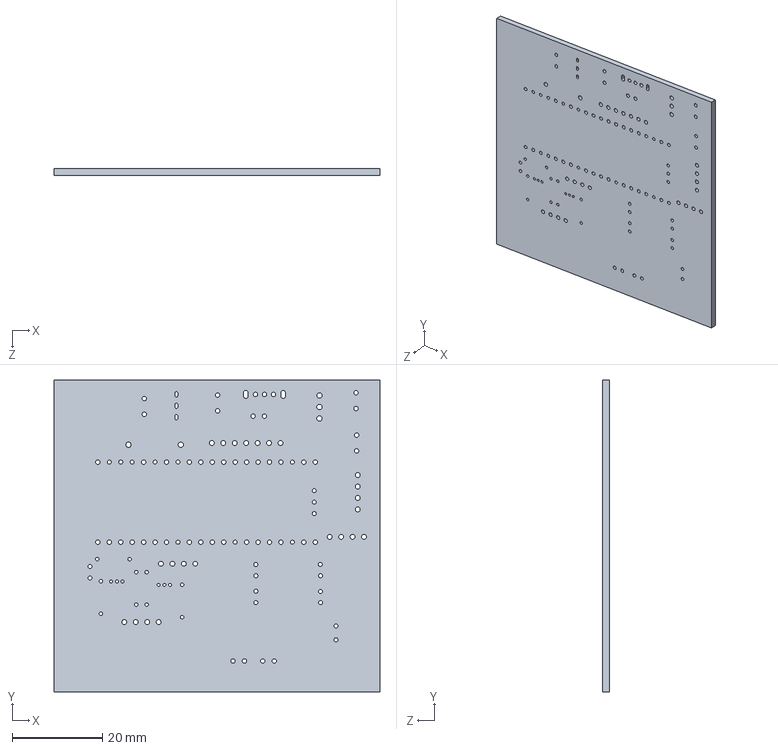
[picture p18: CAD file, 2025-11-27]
projeto_mecanico/Board~1pnl.SLDPRT
72.4 x 69.2 x 1.60 mm

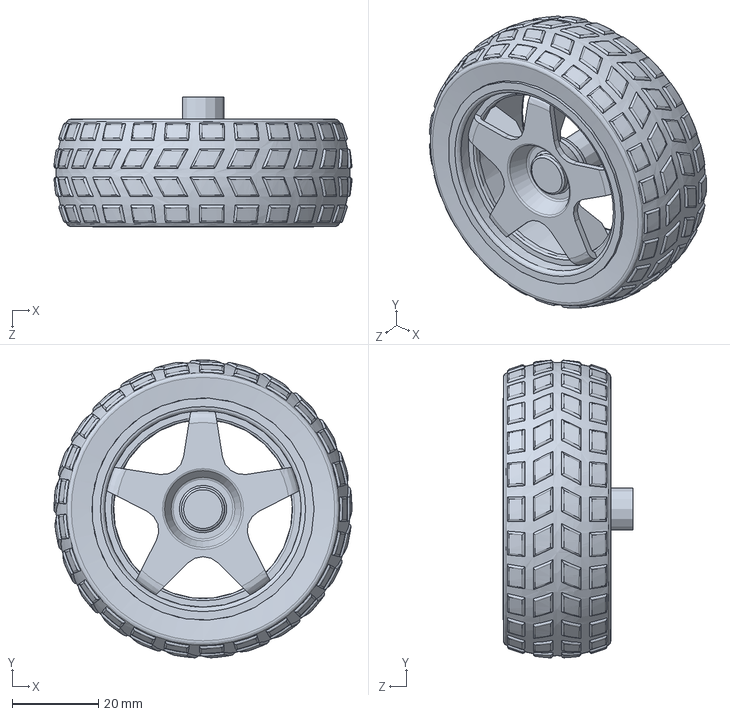
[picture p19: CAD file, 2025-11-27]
projeto_mecanico/Wheel D65x25.SLDPRT
68.9 x 68.8 x 30.0 mm

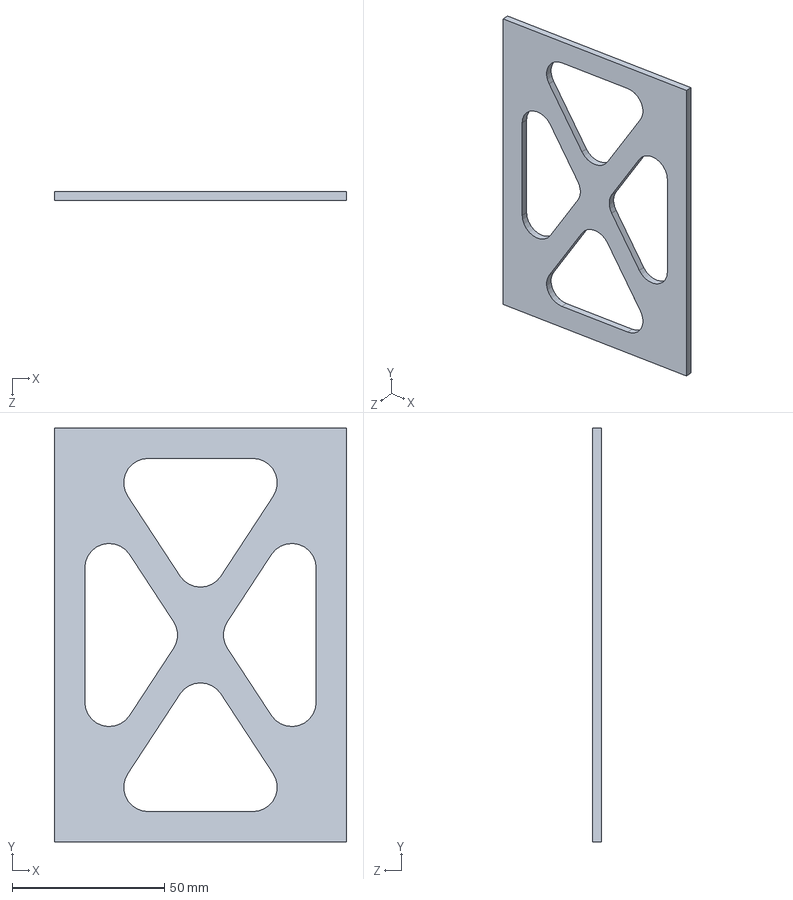
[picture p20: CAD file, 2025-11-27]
projeto_mecanico/prateleira.SLDPRT
96.0 x 136.0 x 3.00 mm

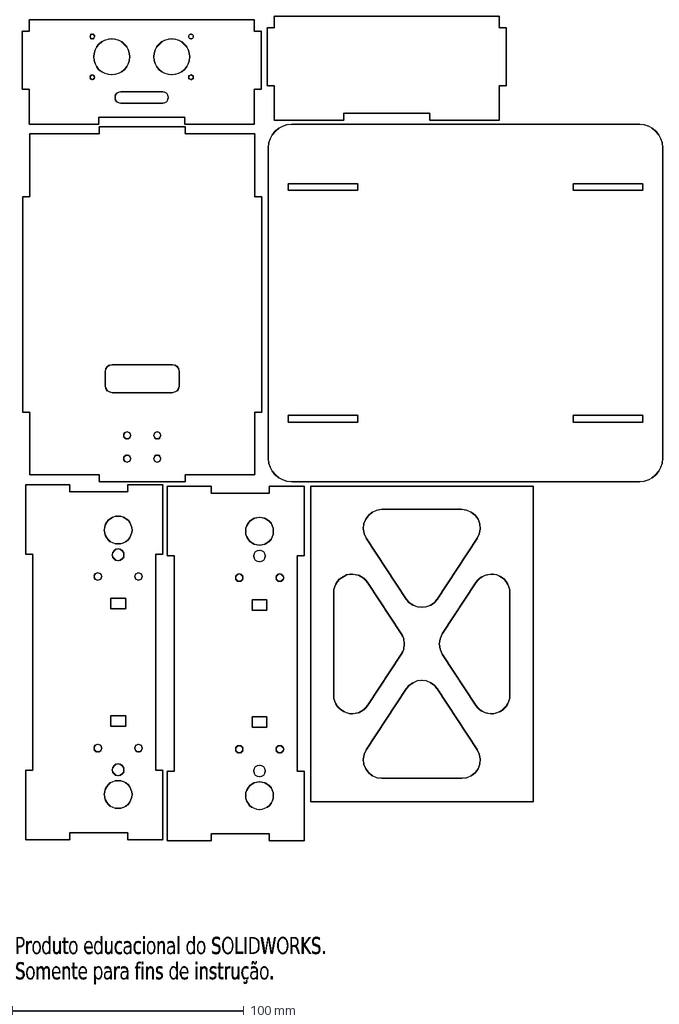
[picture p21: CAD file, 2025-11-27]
projeto_mecanico/corte.DXF
Produto educacional do SOLIDWORKS.
Somente para fins de instrução.

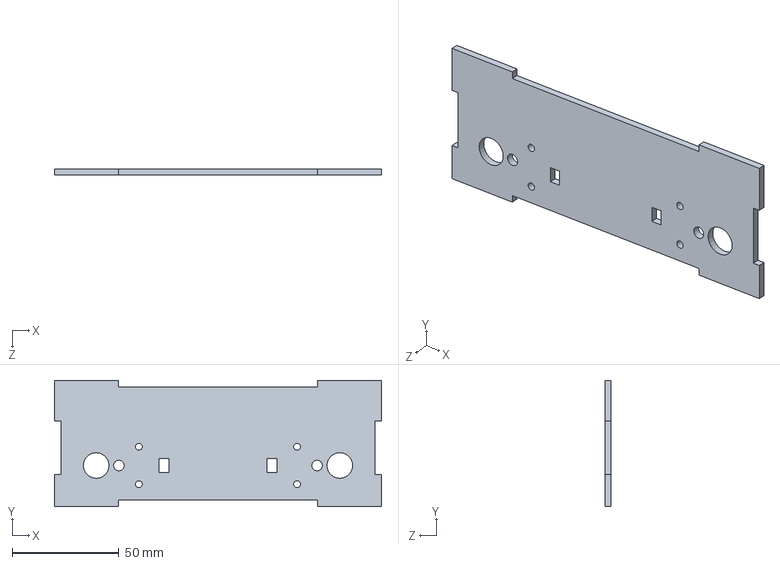
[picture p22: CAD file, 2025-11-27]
projeto_mecanico/lateral.SLDPRT
153.0 x 59.0 x 3.00 mm

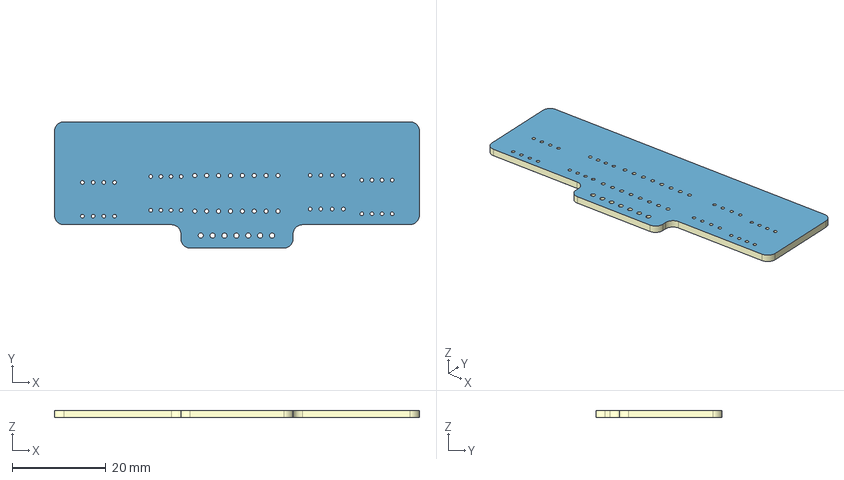
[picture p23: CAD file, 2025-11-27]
projeto_mecanico/barra_sensores.step
78.0 x 27.0 x 1.60 mm
Board~J4cb
TopCopper~J4cb
BottomCopper~J4cb
TopFpcStiffener~J4cb
BottomFpcStiffener~J4cb

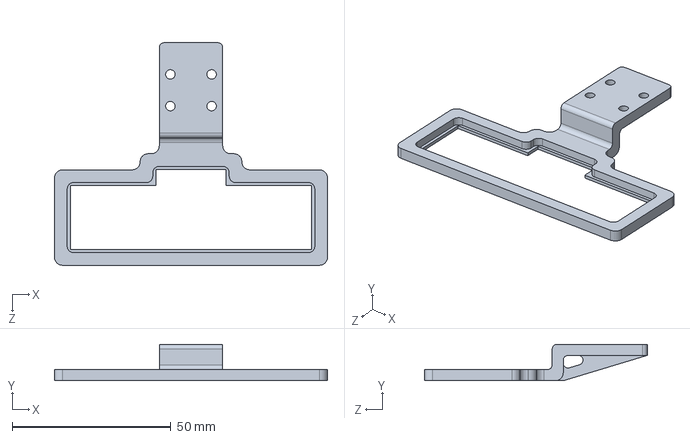
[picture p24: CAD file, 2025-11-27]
projeto_mecanico/suporte_barra.SLDPRT
86.1 x 11.5 x 70.2 mm

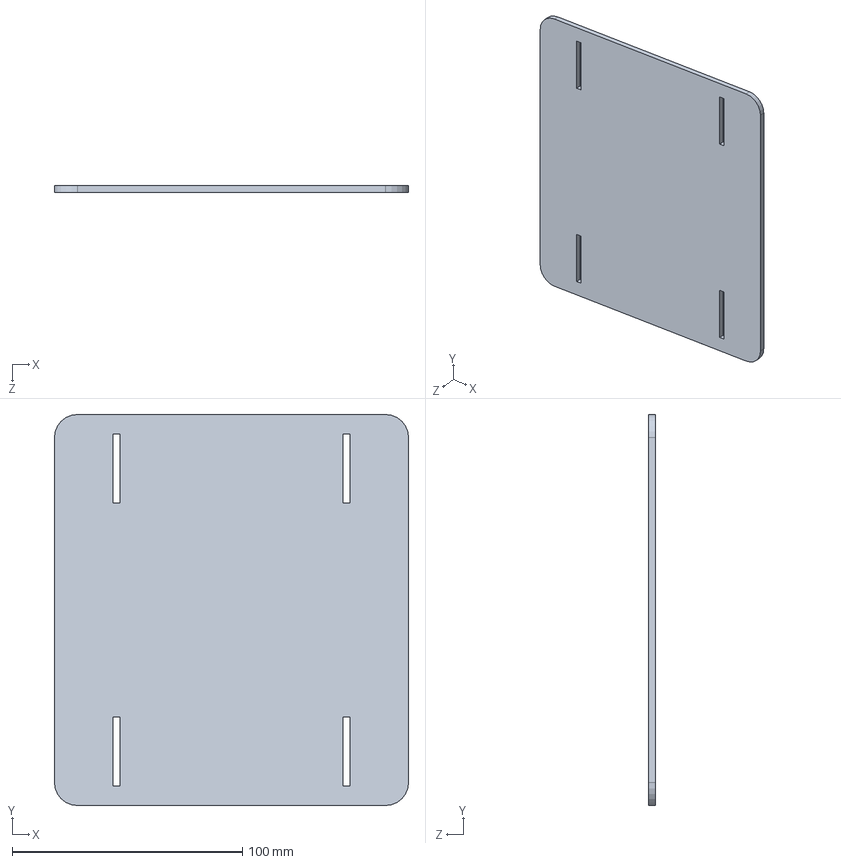
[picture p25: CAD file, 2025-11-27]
projeto_mecanico/mesa.SLDPRT
154.0 x 170.0 x 3.00 mm

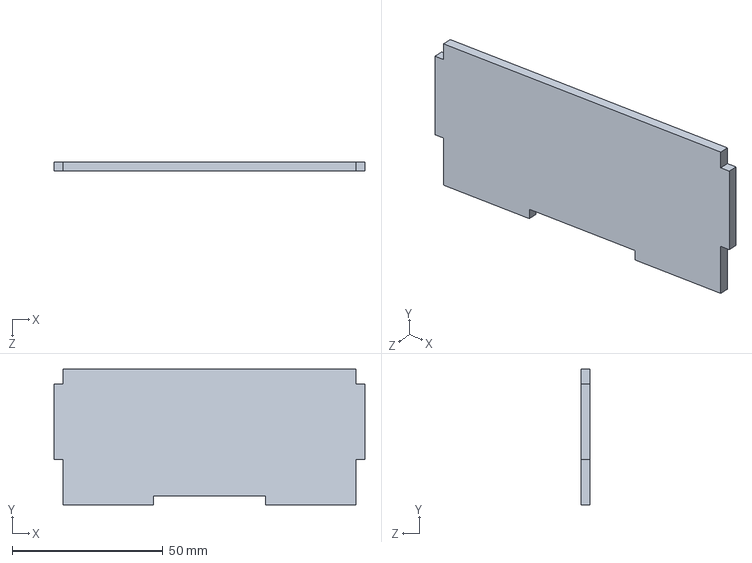
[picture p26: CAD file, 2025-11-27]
projeto_mecanico/tras.SLDPRT
103.0 x 45.0 x 3.00 mm

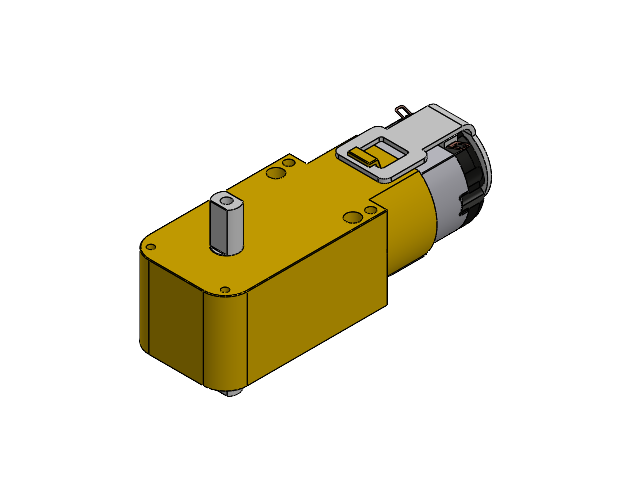
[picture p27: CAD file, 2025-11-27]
projeto_mecanico/motor_amarelo.SLDASM
dc motor.stp
Nody
Axe
Belt

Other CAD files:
projeto_mecanico/Mini Gear DC Motor 6 V Yellow.SLDASM
projeto_mecanico/Belt.SLDPRT
projeto_mecanico/dc motor.stp.SLDPRT
projeto_mecanico/placa_principal.step
projeto_mecanico/Nody.SLDPRT
projeto_mecanico/Board~J4cb.SLDPRT
projeto_mecanico/Axe.SLDPRT
projeto_mecanico/barra_sensores.SLDASM
projeto_mecanico/base.SLDPRT
projeto_mecanico/placa_principal.SLDASM

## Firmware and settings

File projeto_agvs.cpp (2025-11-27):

#include <stdio.h>
#include <math.h>
#include <string.h>
#include "pico/stdlib.h"
#include "hardware/adc.h"
#include "hardware/timer.h"
#include "hardware/irq.h"
#include "hardware/i2c.h"
#include "hardware/uart.h"

#include "sensors.hpp"
#include "motors.hpp"
#include "gyro.hpp"
#include "agv_commands.h"

#include "bt_kmn/bluetooth.h"

SensorArray sensors(18, 19, 20, 26); // Sensores OK
MotorL298N left_motor(11, 14, 15);
MotorL298N right_motor(10, 12, 13);

Ultrasonic ultrasonic(2, 3); // Ultrassom OK

BluetoothConfig bt_config = {
    .uart = uart1,
    .baudrate = 9600,
    .rx_pin = 9,
    .tx_pin = 8
};

uint16_t aux;

int16_t base_speed = 800;
int16_t correction = 0;

float kp = 1.75f;
float ki = 0.0f;
float kd = 520.0f;
float last_error = 0.0f;
float integral = 0.0f;
bool object_detected = false;

uint32_t timer = 0;
#define TIME_STEP_US 10000 // 10 ms

uint32_t last_distance = 0;
int16_t left_pwm = 0;
int16_t right_pwm = 0;
float line_error = 0.0f;

// Robot state control
bool robot_enabled = false;  // Robot starts disabled

// Timer interrupt callback for Bluetooth telemetry
bool timer_callback(struct repeating_timer *t) {
    char msg[64];
    // Format: "L:<left_pwm>,R:<right_pwm>,E:<error>,D:<distance>"
    snprintf(msg, sizeof(msg), "L:%d,R:%d,E:%.2f,D:%lu\n", 
             left_pwm, right_pwm, line_error, last_distance);
    Bluetooth_SendMessage(msg);
    return true; // Keep repeating
}

// Wrapper functions for command system
void set_left_motor_speed(int16_t speed) {
    left_motor.set_speed(speed);
}

void set_right_motor_speed(int16_t speed) {
    right_motor.set_speed(speed);
}

void calibrate_sensors() {
    sensors.calibrate();
}

int main()
{
    stdio_init_all();

    Bluetooth_Setup(bt_config);
    sleep_ms(2000); // Wait for serial to initialize

    // Initialize command system
    AGV_Commands_Setup(set_left_motor_speed, set_right_motor_speed, calibrate_sensors);

    sensors.calibrate();
    sleep_ms(1000);

    struct repeating_timer timer_irq_bt;
    add_repeating_timer_ms(-300, timer_callback, NULL, &timer_irq_bt);

    printf("System ready. Waiting for START command...\n");

    while (true) {
        // Check for incoming commands via Bluetooth
        Bluetooth_ReadMessage();
        if (time_us_32() - timer > TIME_STEP_US) {
            sensors.read_sensors();
            last_distance = ultrasonic.get_distance_mm();
            float error = sensors.calculate_error();
            sensors.print_values();

            correction = kp * error + kd * (error - last_error) + ki * integral;
            last_error = error;
            integral += error;
            int16_t left_speed = base_speed + correction;
            int16_t right_speed = base_speed - correction;
    
            // Update global variables for Bluetooth transmission
            left_pwm = left_speed;
            right_pwm = right_speed;
            line_error = error;
    
            // Check if robot is enabled and no obstacle
            if (robot_enabled) {
                if (last_distance > 0 && last_distance < 120) { // Obstacle detected
                    left_speed = 0;
                    right_speed = 0;
                    object_detected = true;
                } else {
                    object_detected = false;
                }
                
                left_motor.set_speed(left_speed);
                right_motor.set_speed(right_speed);
            } else {
                // Robot disabled - ensure motors are off
                left_motor.set_speed(0);
                right_motor.set_speed(0);
                left_pwm = 0;
                right_pwm = 0;
            }
            
            timer = time_us_32();
        }

    }
}

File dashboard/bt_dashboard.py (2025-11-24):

import serial
import time
from collections import deque
import matplotlib.pyplot as plt
from matplotlib.animation import FuncAnimation
import matplotlib.patches as patches

# Configuration
SERIAL_PORT = 'COM3'  # Change this to your Bluetooth serial port
BAUD_RATE = 9600
TIMEOUT = 1
MAX_POINTS = 100  # Number of data points to display in graphs

# Data storage
timestamps = deque(maxlen=MAX_POINTS)
left_pwm_data = deque(maxlen=MAX_POINTS)
right_pwm_data = deque(maxlen=MAX_POINTS)
error_data = deque(maxlen=MAX_POINTS)
distance_data = deque(maxlen=MAX_POINTS)

# Current values (for display)
current_values = {
    'left_pwm': 0,
    'right_pwm': 0,
    'error': 0.0,
    'distance': 0
}

# Serial connection
ser = None

def parse_telemetry(line):
    """Parse telemetry message format: L:<left_pwm>,R:<right_pwm>,E:<error>,D:<distance>"""
    try:
        line = line.strip()
        parts = line.split(',')
        
        if len(parts) != 4:
            return None
        
        left_pwm = int(parts[0].split(':')[1])
        right_pwm = int(parts[1].split(':')[1])
        error = float(parts[2].split(':')[1])
        distance = int(parts[3].split(':')[1])
        
        return {
            'left_pwm': left_pwm,
            'right_pwm': right_pwm,
            'error': error,
            'distance': distance
        }
    except (ValueError, IndexError):
        return None

def read_serial_data():
    """Read and parse data from serial port"""
    global current_values
    
    if ser and ser.in_waiting > 0:
        try:
            line = ser.readline().decode('utf-8', errors='ignore')
            data = parse_telemetry(line)
            
            if data:
                current_time = time.time()
                
                # Update current values
                current_values = data
                
                # Append to history
                timestamps.append(current_time)
                left_pwm_data.append(data['left_pwm'])
                right_pwm_data.append(data['right_pwm'])
                error_data.append(data['error'])
                distance_data.append(data['distance'])
        except Exception as e:
            print(f"Error reading serial: {e}")

def init_plot():
    """Initialize the plot"""
    fig = plt.figure(figsize=(14, 9))
    fig.suptitle('AGV Telemetry Dashboard', fontsize=16, fontweight='bold')
    
    # Create grid layout
    gs = fig.add_gridspec(3, 2, hspace=0.35, wspace=0.3)
    
    # Motor PWM plot
    ax1 = fig.add_subplot(gs[0, :])
    ax1.set_title('Motor PWM Values')
    ax1.set_ylabel('PWM')
    ax1.set_xlabel('Time (s)')
    ax1.grid(True, alpha=0.3)
    ax1.set_ylim(-1000, 1000)
    
    # Line error plot
    ax2 = fig.add_subplot(gs[1, 0])
    ax2.set_title('Line Following Error')
    ax2.set_ylabel('Error')
    ax2.set_xlabel('Time (s)')
    ax2.grid(True, alpha=0.3)
    ax2.axhline(y=0, color='r', linestyle='--', alpha=0.5)
    
    # Distance plot
    ax3 = fig.add_subplot(gs[1, 1])
    ax3.set_title('Ultrasonic Distance')
    ax3.set_ylabel('Distance (mm)')
    ax3.set_xlabel('Time (s)')
    ax3.grid(True, alpha=0.3)
    
    # Current values display
    ax4 = fig.add_subplot(gs[2, :])
    ax4.axis('off')
    
    return fig, (ax1, ax2, ax3, ax4)

def update_plot(frame, axes):
    """Update plot with new data"""
    ax1, ax2, ax3, ax4 = axes
    
    # Read new data
    read_serial_data()
    
    if len(timestamps) == 0:
        return
    
    # Convert timestamps to relative seconds
    start_time = timestamps[0]
    time_axis = [t - start_time for t in timestamps]
    
    # Clear and update Motor PWM plot
    ax1.clear()
    ax1.set_title('Motor PWM Values')
    ax1.set_ylabel('PWM')
    ax1.set_xlabel('Time (s)')
    ax1.grid(True, alpha=0.3)
    ax1.plot(time_axis, left_pwm_data, label='Left Motor', color='blue', linewidth=2)
    ax1.plot(time_axis, right_pwm_data, label='Right Motor', color='green', linewidth=2)
    ax1.legend(loc='upper right')
    ax1.set_ylim(-1000, 1000)
    
    # Clear and update Error plot
    ax2.clear()
    ax2.set_title('Line Following Error')
    ax2.set_ylabel('Error')
    ax2.set_xlabel('Time (s)')
    ax2.grid(True, alpha=0.3)
    ax2.axhline(y=0, color='r', linestyle='--', alpha=0.5)
    ax2.plot(time_axis, error_data, color='orange', linewidth=2)
    ax2.fill_between(time_axis, error_data, alpha=0.3, color='orange')
    
    # Clear and update Distance plot
    ax3.clear()
    ax3.set_title('Ultrasonic Distance')
    ax3.set_ylabel('Distance (mm)')
    ax3.set_xlabel('Time (s)')
    ax3.grid(True, alpha=0.3)
    ax3.plot(time_axis, distance_data, color='red', linewidth=2)
    ax3.fill_between(time_axis, distance_data, alpha=0.3, color='red')
    
    # Update current values display
    ax4.clear()
    ax4.axis('off')
    
    # Create nice boxes for current values
    box_y = 0.5
    box_width = 0.22
    box_height = 0.8
    
    boxes = [
        {'x': 0.02, 'label': 'Left PWM', 'value': f"{current_values['left_pwm']}", 'color': '#3498db'},
        {'x': 0.27, 'label': 'Right PWM', 'value': f"{current_values['right_pwm']}", 'color': '#2ecc71'},
        {'x': 0.52, 'label': 'Error', 'value': f"{current_values['error']:.2f}", 'color': '#e74c3c'},
        {'x': 0.77, 'label': 'Distance', 'value': f"{current_values['distance']} mm", 'color': '#9b59b6'},
    ]
    
    for box in boxes:
        # Draw box
        rect = patches.FancyBboxPatch(
            (box['x'], box_y - box_height/2), box_width, box_height,
            boxstyle="round,pad=0.01", 
            linewidth=2, 
            edgecolor=box['color'], 
            facecolor=box['color'],
            alpha=0.2,
            transform=ax4.transAxes
        )
        ax4.add_patch(rect)
        
        # Add label
        ax4.text(box['x'] + box_width/2, box_y + 0.15, box['label'],
                ha='center', va='center', fontsize=10, fontweight='bold',
                transform=ax4.transAxes)
        
        # Add value
        ax4.text(box['x'] + box_width/2, box_y - 0.15, box['value'],
                ha='center', va='center', fontsize=14, fontweight='bold',
                color=box['color'], transform=ax4.transAxes)
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

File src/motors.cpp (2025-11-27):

#include "motors.hpp"

Motor::Motor(uint pwm1_pin, uint pwm2_pin)
    : _pwm1_pin(pwm1_pin), _pwm2_pin(pwm2_pin) {
    gpio_set_function(_pwm1_pin, GPIO_FUNC_PWM);
    gpio_set_function(_pwm2_pin, GPIO_FUNC_PWM);

    pwm_config config = pwm_get_default_config();
    // pwm config -> 1023 wrap and 20kHz frequency
    // base clock -> 125MHz
    pwm_config_set_wrap(&config, MAX_WRAP);
    pwm_config_set_clkdiv(&config, 6.1f); // 125MHz / 6.1 / 1024 = ~20kHz
    _slice_num1 = pwm_gpio_to_slice_num(_pwm1_pin);
    _slice_num2 = pwm_gpio_to_slice_num(_pwm2_pin);
    pwm_init(_slice_num1, &config, true);
    pwm_init(_slice_num2, &config, true);
}

void Motor::set_speed(int16_t speed) {
    if (speed > MAX_WRAP) {
        speed = MAX_WRAP;
    } else if (speed < -MAX_WRAP) {
        speed = -MAX_WRAP;
    }
    if (speed >= 0) {
        pwm_set_gpio_level(_pwm1_pin, speed);
        pwm_set_gpio_level(_pwm2_pin, 0);
    } else {
        pwm_set_gpio_level(_pwm1_pin, 0);
        pwm_set_gpio_level(_pwm2_pin, -speed);
    }
}

MotorL298N::MotorL298N(uint enable_pin, uint in1_pin, uint in2_pin)
    : _enable_pin(enable_pin), _in1_pin(in1_pin), _in2_pin(in2_pin) {
    gpio_set_function(_enable_pin, GPIO_FUNC_PWM);
    gpio_init(_in1_pin);
    gpio_set_dir(_in1_pin, GPIO_OUT);
    gpio_init(_in2_pin);
    gpio_set_dir(_in2_pin, GPIO_OUT);

    pwm_config config = pwm_get_default_config();
    // pwm config -> 1023 wrap and 20kHz frequency
    // base clock -> 125MHz
    pwm_config_set_wrap(&config, MAX_WRAP);
    pwm_config_set_clkdiv(&config, 6.1f); // 125MHz / 6.1 / 1024 = ~20kHz
    _slice_num = pwm_gpio_to_slice_num(_enable_pin);
    pwm_init(_slice_num, &config, true);
}

void MotorL298N::set_speed(int16_t speed) {
    if (speed > MAX_WRAP) {
        speed = MAX_WRAP;
    } else if (speed < -MAX_WRAP) {
        speed = -MAX_WRAP;
    }
    if (speed >= 0) {
        gpio_put(_in1_pin, 1);
        gpio_put(_in2_pin, 0);
        pwm_set_gpio_level(_enable_pin, speed);
    } else {
        gpio_put(_in1_pin, 0);
        gpio_put(_in2_pin, 1);
        pwm_set_gpio_level(_enable_pin, -speed);
    }
}

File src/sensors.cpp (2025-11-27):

#include "sensors.hpp"
#include "pico/stdlib.h"
#include "hardware/adc.h"
#include <stdio.h>

SensorArray::SensorArray(uint bit0, uint bit1, uint bit2, uint adc)
    : _bit_0_pin(bit0), _bit_1_pin(bit1), _bit_2_pin(bit2), _adc_pin(adc) {
    gpio_init(_bit_0_pin);
    gpio_set_dir(_bit_0_pin, GPIO_OUT);
    gpio_init(_bit_1_pin);
    gpio_set_dir(_bit_1_pin, GPIO_OUT);
    gpio_init(_bit_2_pin);
    gpio_set_dir(_bit_2_pin, GPIO_OUT);

    adc_init();
    adc_gpio_init(_adc_pin);
    adc_select_input(0); // Assuming ADC channel 0 is used
}

void SensorArray::read_sensors() {
    for (uint8_t i = 0; i < NUM_SENSORS; i++) {
        _set_mux_channel(i);
        sleep_us(10); // Allow mux output to settle before ADC reading
        _sensor_array[i] = _read_adc();
    }
}

uint16_t SensorArray::get_sensor_value(uint8_t index) {
    if (index < NUM_SENSORS) {
        return _sensor_array[index];
    }
    return 0;
}

void SensorArray::_set_mux_channel(uint8_t channel) {
    gpio_put(_bit_0_pin, (channel & 0x01));
    gpio_put(_bit_1_pin, (channel >> 1) & 0x01);
    gpio_put(_bit_2_pin, (channel >> 2) & 0x01);
    sleep_us(10);
}

uint16_t SensorArray::_read_adc() {
    adc_select_input(0); // Ensure the correct ADC channel is selected
    sleep_us(10); // Give ADC time to switch and settle
    return adc_read();
}

float SensorArray::calculate_error() {
    int32_t weighted_sum = 0;
    uint16_t total_value = 0;

    for (uint8_t i = 0; i < NUM_SENSORS; i++) {
        // normalizes the readings between 0 and 1000
        uint16_t sensor_value = (get_sensor_value(i) - _min_sensor_values[i]) * 1000 /
                                (_max_sensor_values[i] - _min_sensor_values[i]);
        if (sensor_value > 1000) sensor_value = 1000;
        if (sensor_value < 0) sensor_value = 0;
        
        weighted_sum += sensor_value * (i * 1000); // Weight by position
        total_value += sensor_value;
    }

    if (total_value == 0) {
        return 0.0f; // Avoid division by zero
    }

    return static_cast<float>((weighted_sum / total_value) - SENSOR_OFFSET); // Center around zero
}

void SensorArray::calibrate() {
    // Initialize min and max arrays
    for (uint8_t i = 0; i < NUM_SENSORS; i++) {
        _max_sensor_values[i] = 0;
        _min_sensor_values[i] = 4095; // Max possible ADC value
    }

    // Perform calibration readings
    for (uint16_t sample = 0; sample < 20000; sample++) {
        read_sensors();
        for (uint8_t i = 0; i < NUM_SENSORS; i++) {
            uint16_t value = get_sensor_value(i);
            if (value > _max_sensor_values[i]) {
                _max_sensor_values[i] = value;
            }
            if (value < _min_sensor_values[i]) {
                _min_sensor_values[i] = value;
            }
        }
    }
}

void SensorArray::print_values() {
    for (uint8_t i = 0; i < NUM_SENSORS; i++) {
        printf("%d\t", get_sensor_value(i));
    }
    printf("\n");
}

Ultrasonic::Ultrasonic(uint trigger_pin, uint echo_pin)
    : _trigger_pin(trigger_pin), _echo_pin(echo_pin) {
    // Initialize trigger pin - force low multiple times
    gpio_init(_trigger_pin);
    gpio_set_dir(_trigger_pin, GPIO_OUT);
    gpio_put(_trigger_pin, 0);
    sleep_ms(10);
    gpio_put(_trigger_pin, 0); // Force low again
    
    // Initialize echo pin
    gpio_init(_echo_pin);
    gpio_set_dir(_echo_pin, GPIO_IN);
    gpio_set_pulls(_echo_pin, false, false); // Disable internal pulls for level shifter

    sleep_ms(100); // Longer initial delay for sensor startup
    gpio_put(_trigger_pin, 0); // Ensure trigger is still low
}
void Ultrasonic::_pulse_trigger() {
    gpio_put(_trigger_pin, 0);
    sleep_us(5); // Longer low time for level shifter
    gpio_put(_trigger_pin, 1);
    sleep_us(15); // Slightly longer pulse for reliability through level shifter
    gpio_put(_trigger_pin, 0);
    sleep_us(2); // Small settling time
}

uint32_t Ultrasonic::get_distance_mm() {
    // Ensure trigger starts low, then send pulse
    gpio_put(_trigger_pin, 0);
    sleep_us(2);
    gpio_put(_trigger_pin, 1);
    sleep_us(10);
    gpio_put(_trigger_pin, 0);

    // Wait for echo to go high with timeout
    uint32_t timeout_start = time_us_32();
    while(gpio_get(_echo_pin) == 0) {
        if (time_us_32() - timeout_start > 50000) {
            return 0; // Timeout waiting for echo start
        }
    }
    
    // Measure pulse width with timeout
    uint32_t start_time = time_us_32();
    while(gpio_get(_echo_pin) == 1) {
        if (time_us_32() - start_time > 50000) {
            return 0; // Timeout - pulse too long
        }
    }
    uint32_t pulse_width = time_us_32() - start_time;
    
    // Sanity check pulse duration (150us - 25ms is valid range)
    if (pulse_width < 150 || pulse_width > 25000) {
        return 0; // Invalid reading
    }
    
    // Calculate distance in mm (speed of sound is ~343 m/s = 0.343 mm/us)
    // Distance = (time * speed) / 2 = (pulse_width_us * 0.343 mm/us) / 2
    uint32_t distance_mm = (pulse_width * 343) / 2000;

    return distance_mm;
}

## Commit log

2025-11-27 add proj_mecanico
    [Axe.SLDPRT, Belt.SLDPRT, Board~1pnl.SLDPRT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]
2025-11-27 fix: malha em 10ms
    [projeto_agvs.cpp]
2025-11-27 Revise default PID values for Kp, Kd
    Updated default PID controller values in README.
2025-11-27 fix: default PID values
    [projeto_agvs.cpp]
2025-11-27 fix ultrasonic reading interval 10ms on readme
